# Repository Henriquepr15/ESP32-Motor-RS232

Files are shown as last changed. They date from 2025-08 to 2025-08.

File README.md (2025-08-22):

# ESP32 Motor RS232  

Projeto desenvolvido como parte de um teste prático para posição de Desenvolvedor de Hardware/Firmware.  

## Descrição  
Circuito com ESP32 para acionamento de motor a partir de sinal externo, utilizando reguladores de tensão, conversor buck LM2596, driver de motor e comunicação serial RS232 (MAX3232).  

## Funcionalidades  
- Leitura de sinal externo  
- Acionamento de motor por 10 segundos em nível baixo  
- Envio de mensagens de status via UART RS232  
- LEDs indicadores de funcionamento e debug  

## Estrutura do Projeto  
- Esquemáticos e PCB: Arquivos KiCad  
- Gerber, Drill, PnP e BOM: Saída de fabricação  
- Código em C: Arquivo main.c  
- Documentação: Datasheets e anotações  

## Requisitos de Software  
Código em linguagem C, leitura de entrada digital, controle de saída para o motor, temporização de 10 segundos e comunicação UART.  

## Como Compilar  
O código foi escrito em C padrão, podendo ser adaptado para o ESP32 com ESP-IDF ou Arduino IDE.  

## Requisitos de Hardware  
- ESP32-WROOM-32  
- LM2596 (buck converter)  
- AMS1117-3.3 (regulador LDO)  
- MAX3232 (interface RS232)  
- MOSFET AO3400A  
- Indutor, capacitores, resistores e conectores auxiliares  

## Autor  
Henrique Pires  

## Imagens do projeto  



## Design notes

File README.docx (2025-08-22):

Projeto de Hardware – ESP32 com RS232 e Controle de Motor

Descrição

Este projeto implementa uma placa de desenvolvimento baseada no módulo ESP32-WROOM-32, com suporte a comunicação serial RS-232, controle de motor e alimentação a partir de 12 V.
O circuito inclui conversores de tensão, proteções elétricas e pontos de teste para depuração.

Funcionalidades

- Conversão de 12 V para 5 V (LM2596) e para 3.3 V (AMS1117).
- Comunicação serial compatível com RS-232 (MAX3232 + conector DB9).
- Controle de motor utilizando MOSFET AO3400A e diodo Schottky.
- Proteções contra surtos e inversão de polaridade (fusível, TVS, zener, ferrite bead).
- LEDs indicadores para debug e funcionamento.
- Pontos de teste para facilitar medições.

Estrutura do Projeto

- MCU.kicad_sch – Microcontrolador ESP32 e conexões.
- Power.kicad_sch – Circuito de alimentação.
- Input12V.kicad_sch – Entrada de 12 V e proteções.
- MotorDriver.kicad_sch – Driver de motor.
- RS232.kicad_sch – Comunicação serial RS-232.

Componentes Principais

- ESP32-WROOM-32
- LM2596S-ADJ (buck converter)
- AMS1117-3.3 (LDO)
- MAX3232 (nível RS-232)
- AO3400A (MOSFET de potência)
- Diodos TVS, Schottky e Zener
- Indutor 47 µH (regulador)
- Capacitores e resistores SMD 0805

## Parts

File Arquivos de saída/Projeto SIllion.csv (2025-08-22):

Reference | Qty | Value | DNP | Exclude from BOM | Exclude from Board | Footprint | Datasheet
C5 | 1 | 100µF |  |  |  | Capacitor_SMD:C_0805_2012Metric | ~
C6 | 1 | 1µF |  |  |  | Capacitor_SMD:C_0805_2012Metric | ~
C7,C12,C28 | 3 | 100nF |  |  |  | Capacitor_SMD:C_0805_2012Metric | ~
C8 | 1 | 10 µF |  |  |  | Capacitor_SMD:C_0805_2012Metric | ~
C10 | 1 | 220 µF |  |  |  | Capacitor_SMD:C_0805_2012Metric | ~
C11,C29,C30,C31,C32 | 5 | 100 nF |  |  |  | Capacitor_SMD:C_0805_2012Metric | ~
C13 | 1 | C |  |  |  | Capacitor_SMD:C_0805_2012Metric | ~
C17,C25,C26 | 3 | 10u |  |  |  | Capacitor_SMD:C_0805_2012Metric | ~
C33,C34 | 2 | 100uF |  |  |  | Capacitor_SMD:C_0805_2012Metric | ~
C35,C36 | 2 | 1nF |  |  |  | Capacitor_SMD:C_0805_2012Metric | ~
D1,D9 | 2 | D_TVS |  |  |  | Diode_SMD:D_SMA | ~
D2,D7,D10 | 3 | D_Schottky |  |  |  | Diode_SMD:D_SMA | ~
D8 | 1 | D_Zener |  |  |  | Diode_SMD:D_SOD-123 | ~
D11,D12 | 2 | LED |  |  |  | LED_SMD:LED_0805_2012Metric | ~
F1 | 1 | Fuse |  |  |  | Fuse:Fuse_1812_4532Metric | ~
FB1 | 1 | FerriteBead |  |  |  | Inductor_SMD:L_0805_2012Metric | ~
J1,J3,J5 | 3 | Conn_01x02 |  |  |  | Connector_PinHeader_2.54mm:PinHeader_1x02_P2.54mm_Vertical | ~
J4 | 1 | DE9_Pins |  |  |  | Connector_Dsub:DSUB-9_Pins_Horizontal_P2.77x2.84mm_EdgePinOffset7.70mm_Housed_MountingHolesOffset9.12mm | ~
J6 | 1 | Conn_01x06 |  |  |  | Connector_PinHeader_2.54mm:PinHeader_1x06_P2.54mm_Vertical | ~
L1 | 1 | L |  |  |  | Inductor_SMD:L_Bourns_SRN6045TA | ~
Q3 | 1 | AO3400A |  |  |  | Package_TO_SOT_SMD:SOT-23 | http://www.aosmd.com/pdfs/datasheet/AO3400A.pdf
R8 | 1 | 3,65 kΩ |  |  |  | Resistor_SMD:R_0805_2012Metric | ~
R9 | 1 | 1,20 kΩ |  |  |  | Resistor_SMD:R_0805_2012Metric | ~
R10 | 1 | 100kΩ |  |  |  | Resistor_SMD:R_0805_2012Metric | ~
R11 | 1 | 33kΩ |  |  |  | Resistor_SMD:R_0805_2012Metric | ~
R13 | 1 | 1kΩ |  |  |  | Resistor_SMD:R_0805_2012Metric | ~
R14,R26 | 2 | 100 kΩ |  |  |  | Resistor_SMD:R_0805_2012Metric | ~
R27,R28 | 2 | 10kΩ |  |  |  | Resistor_SMD:R_0805_2012Metric | ~
R29,R30 | 2 | 330Ω |  |  |  | Resistor_SMD:R_0805_2012Metric | ~
SW1,SW2 | 2 | SW_Push |  |  |  | Button_Switch_SMD:SW_SPST_TL3342 | ~
TP1,TP2,TP3,TP4,TP5 | 5 | TestPoint |  |  |  | TestPoint:TestPoint_Pad_1.5x1.5mm | ~
U5 | 1 | LM2596S-ADJ |  |  |  | Package_TO_SOT_SMD:TO-263-5_TabPin3 | http://www.ti.com/lit/ds/symlink/lm2596.pdf
U6 | 1 | MAX3232 |  |  |  | Package_SO:SOIC-16_3.9x9.9mm_P1.27mm | https://datasheets.maximintegrated.com/en/ds/MAX3222-MAX3241.pdf
U7 | 1 | AMS1117-3.3 |  |  |  | Package_TO_SOT_SMD:SOT-223-3_TabPin2 | http://www.advanced-monolithic.com/pdf/ds1117.pdf
U8 | 1 | ESP32-WROOM-32 |  |  |  | RF_Module:ESP32-WROOM-32 | https://www.espressif.com/sites/default/files/documentation/esp32-wroom-32_datasheet_en.pdf

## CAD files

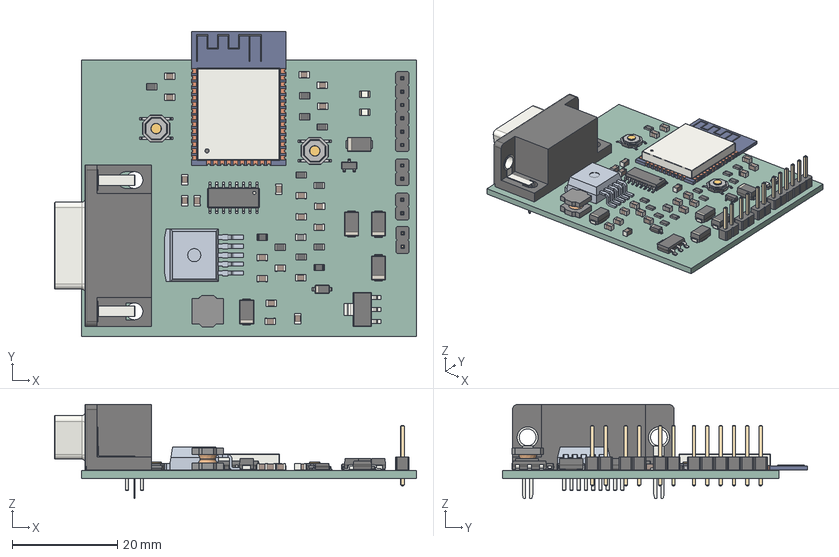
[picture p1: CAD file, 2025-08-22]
Arquivos de saída/Projeto SIllion.step
68.9 x 58.1 x 17.9 mm
C_0805_2012Metric x 20
PinHeader_1x06_P2.54mm_Vertical
Projeto SIllion 1.5.1
R_0805_2012Metric x 11
SW_SPST_TL3342 x 2
SOT-223
D_SMA x 5
SOT-23
ESP32-WROOM-32
L_Bourns_SRN6045TA
L_0805_2012Metric
LED_0805_2012Metric x 2
DSUB-9_Pins_Horizontal_P2.77x2.84mm_EdgePinOffset7.70mm_Housed_ MountingHolesOffset9.12mm
D_SOD-123
PinHeader_1x02_P2.54mm_Vertical x 3
SOIC-16_3.9x9.9mm_P1.27mm
Projeto SIllion_PCB

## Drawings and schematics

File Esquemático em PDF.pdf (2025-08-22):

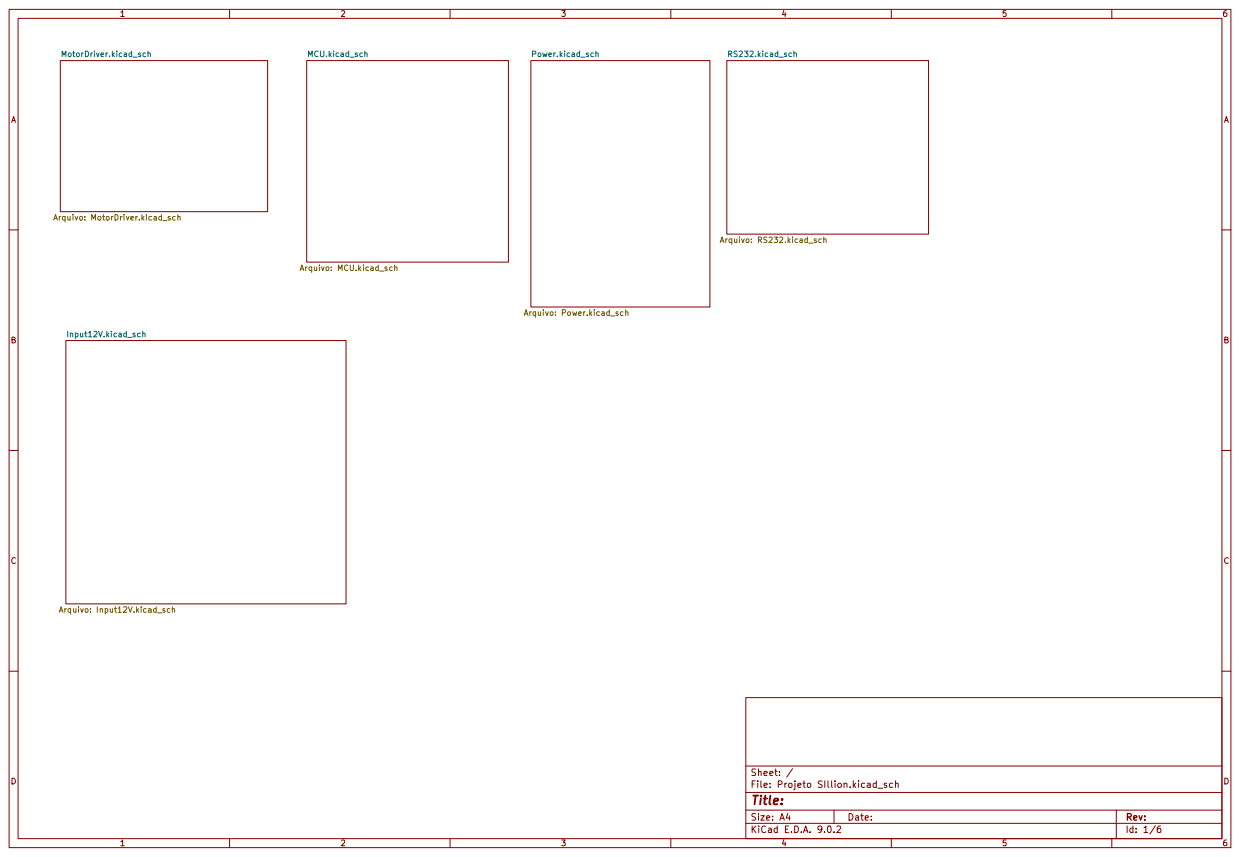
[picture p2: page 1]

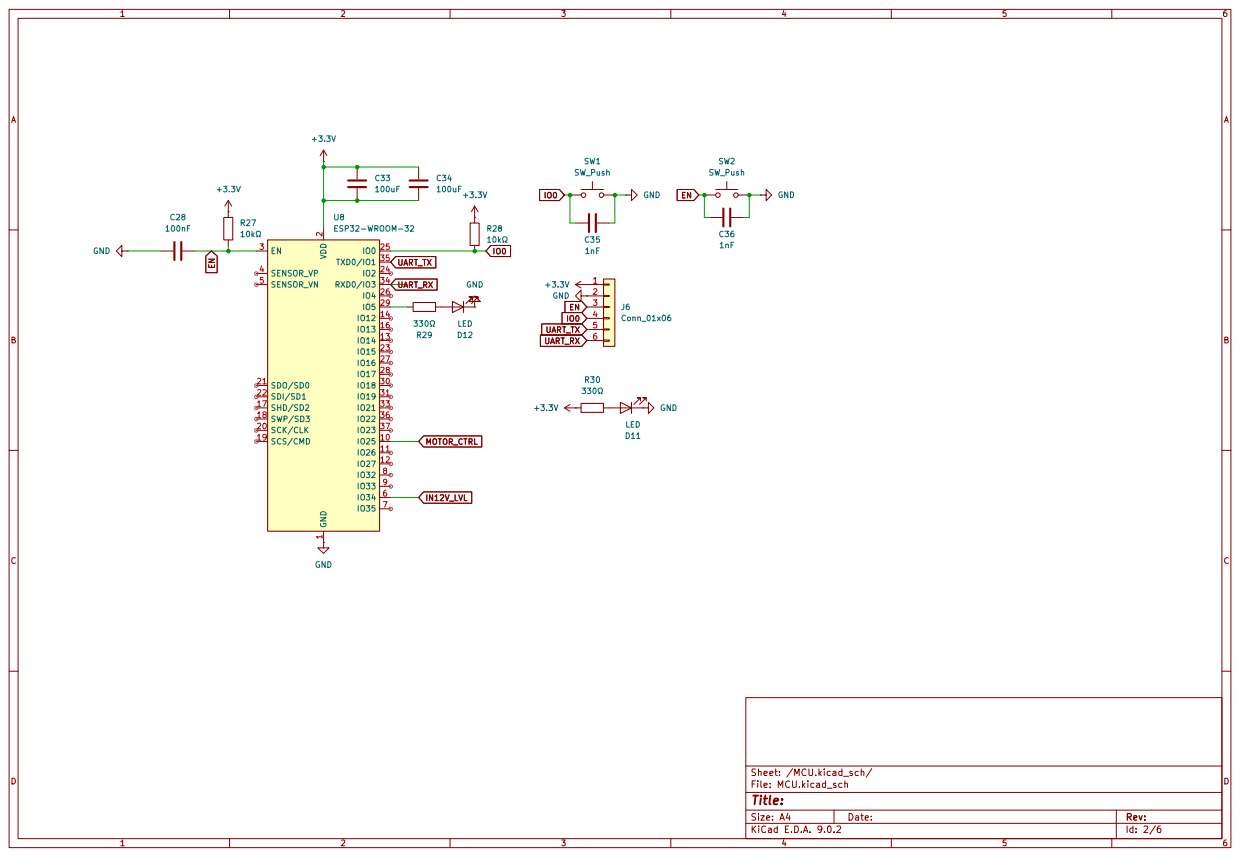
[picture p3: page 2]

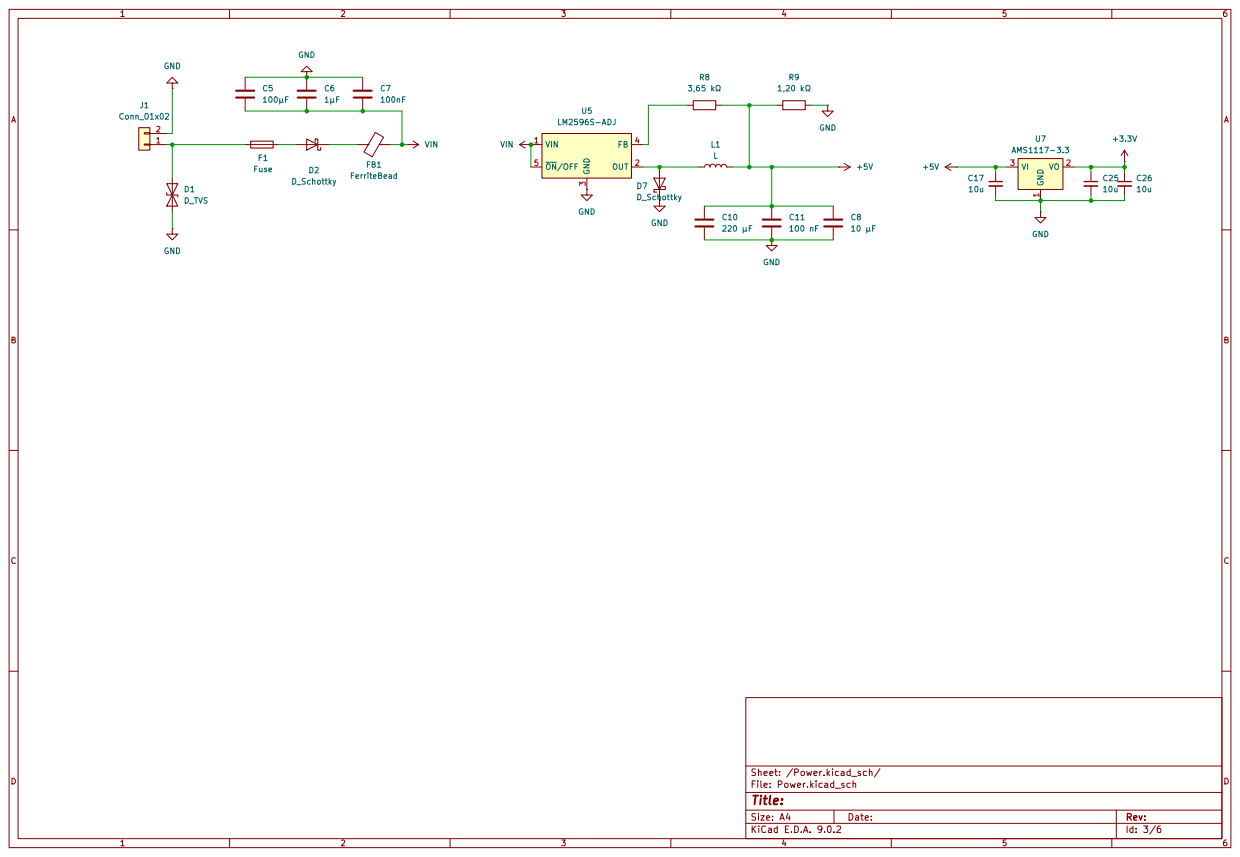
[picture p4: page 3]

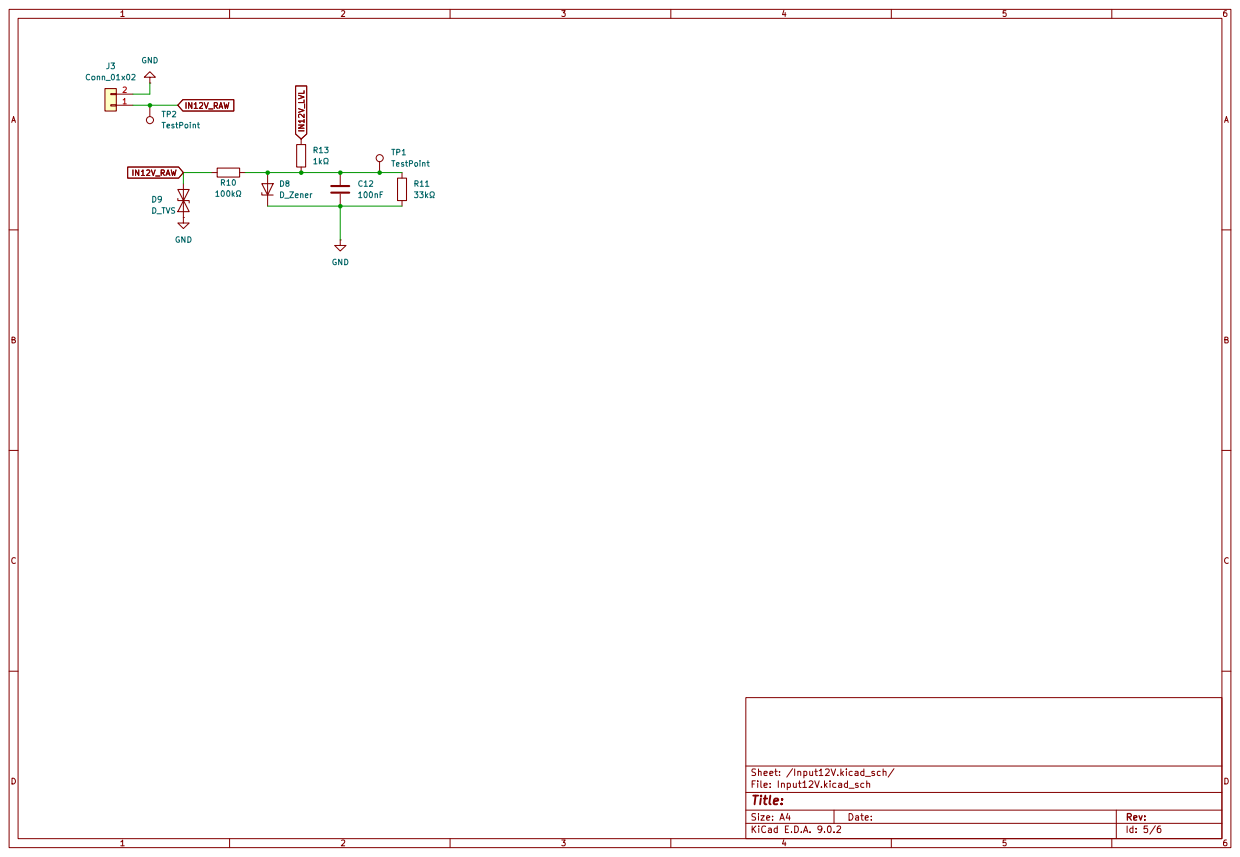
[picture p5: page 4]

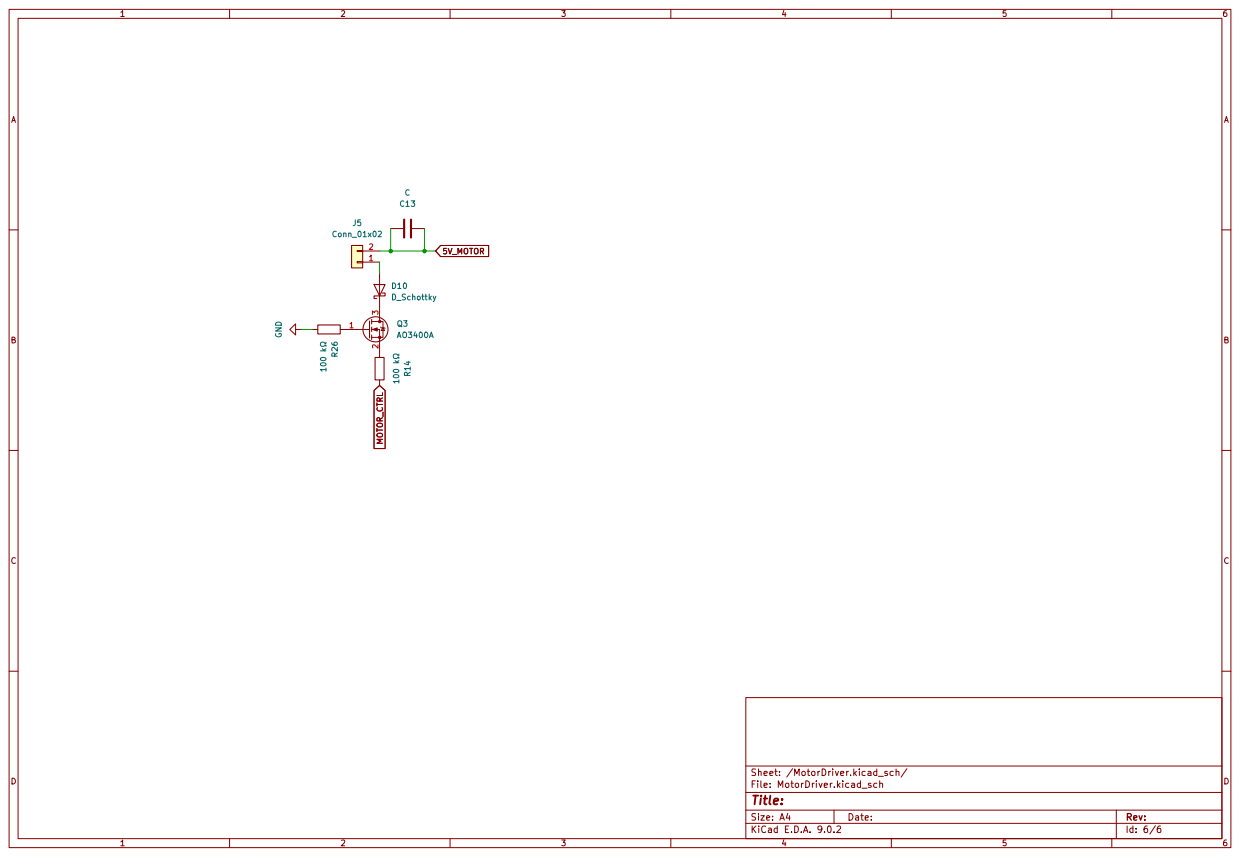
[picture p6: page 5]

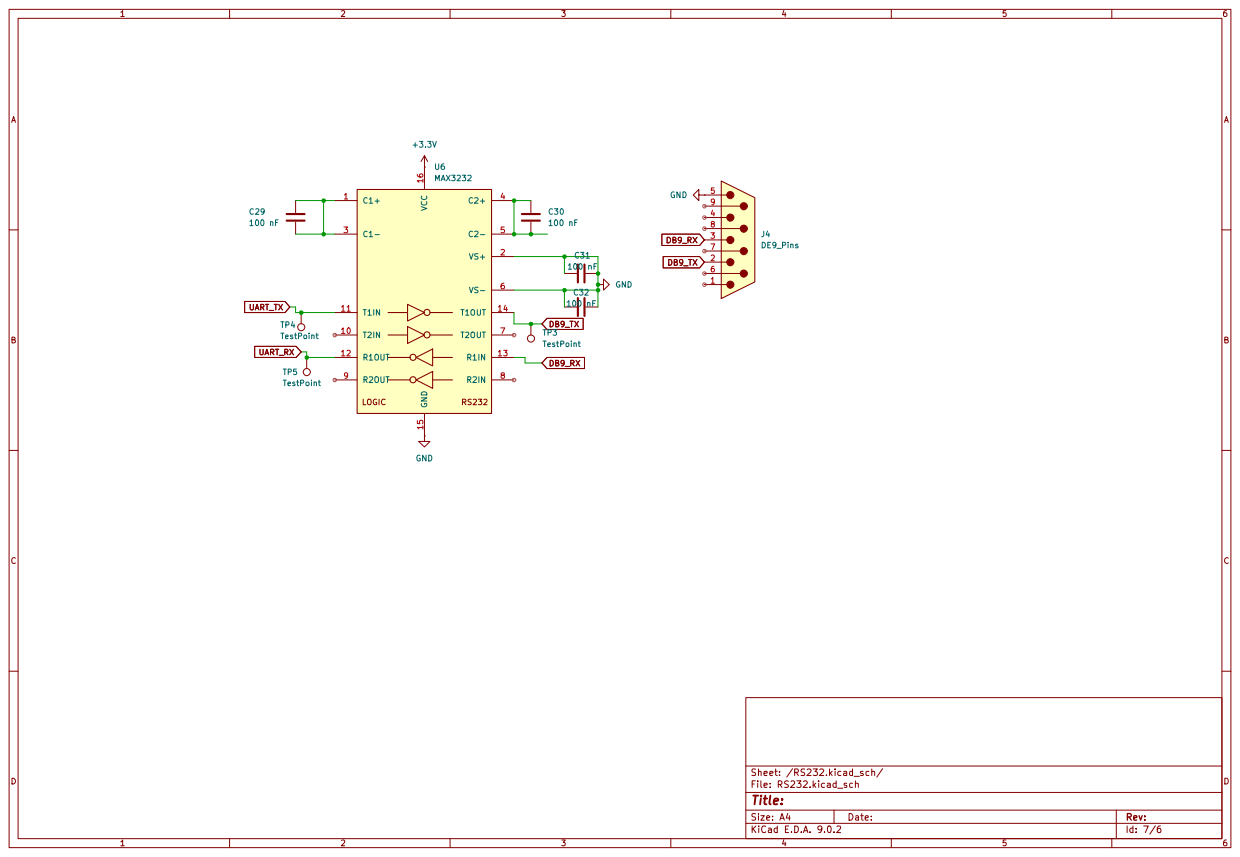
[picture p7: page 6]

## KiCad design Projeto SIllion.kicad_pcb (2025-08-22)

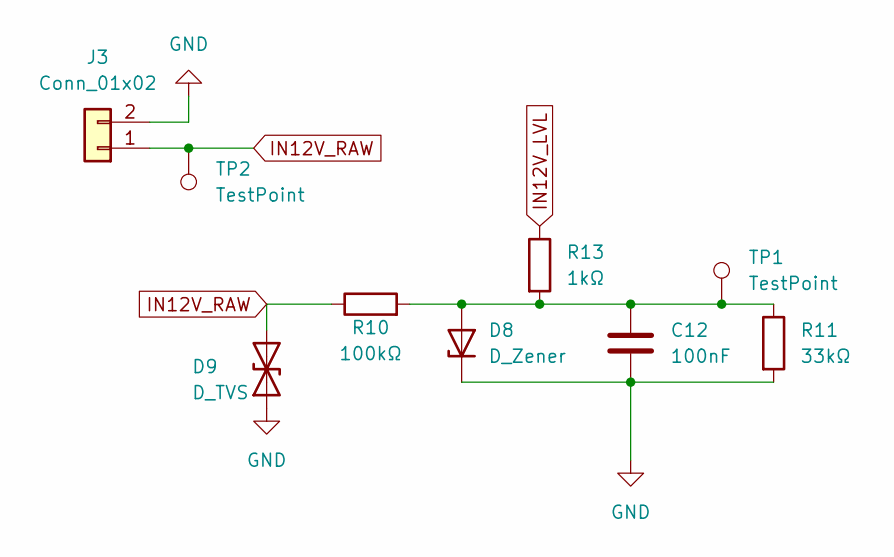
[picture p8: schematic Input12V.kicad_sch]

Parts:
C12: 100nF; C_0805_2012Metric
D8: D_Zener; D_SOD-123
D9: D_TVS; D_SMA
J3: Conn_01x02; PinHeader_1x02_P2.54mm_Vertical
R10: 100kΩ; R_0805_2012Metric
R11: 33kΩ; R_0805_2012Metric
R13: 1kΩ; R_0805_2012Metric
TP1, TP2: TestPoint; TestPoint_Pad_1.5x1.5mm

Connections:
GND: C12.2, D8.1 (K), D9.1 (A1), J3.2, R11.2; also elsewhere on the board
IN12V_LVL: R13.1; also elsewhere on the board
IN12V_RAW: D9.2 (A2), J3.1, R10.1, TP2.1
unnamed: C12.1, D8.2 (A), R10.2, R11.1, R13.2, TP1.1

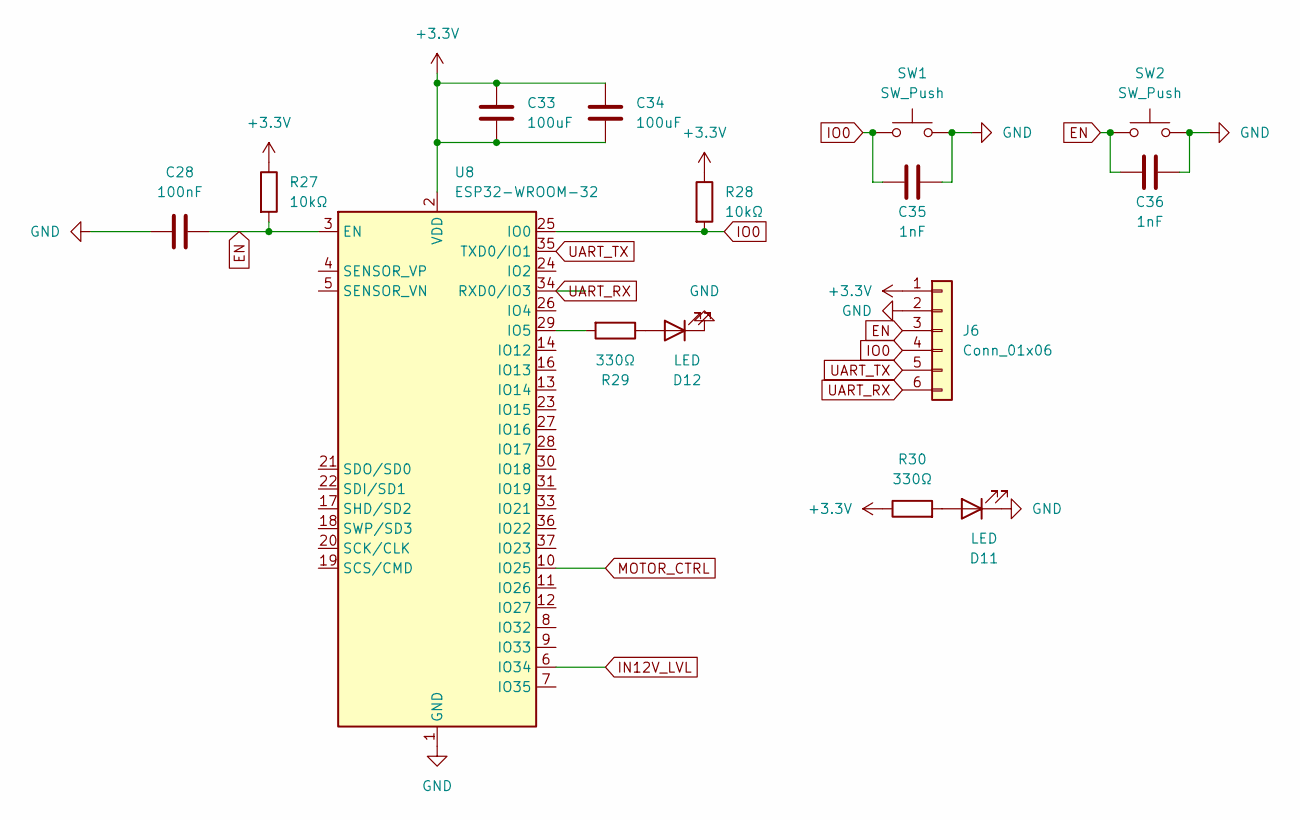
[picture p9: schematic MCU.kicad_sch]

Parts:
C28: 100nF; C_0805_2012Metric
C33, C34: 100uF; C_0805_2012Metric
C35, C36: 1nF; C_0805_2012Metric
D11, D12: LED; LED_0805_2012Metric
J6: Conn_01x06; PinHeader_1x06_P2.54mm_Vertical
R27, R28: 10kΩ; R_0805_2012Metric
R29, R30: 330Ω; R_0805_2012Metric
SW1, SW2: SW_Push; SW_SPST_TL3342
U8: ESP32-WROOM-32

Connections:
+3.3V: C33.1, C33.2, C34.1, C34.2, J6.1, R27.1, R28.1, R30.1, U8.2 (VDD); also elsewhere on the board
EN: C28.2, C36.1, J6.3, R27.2, SW2.1, U8.3 (EN)
GND: C28.1, C35.2, C36.2, D11.1 (K), D12.1 (K), J6.2, SW1.2, SW2.2, U8.1 (GND), U8.15 (GND), U8.38 (GND), U8.39 (GND); also elsewhere on the board
IN12V_LVL: U8.6 (IO34); also elsewhere on the board
IO0: C35.1, J6.4, R28.2, SW1.1, U8.25 (IO0)
MOTOR_CTRL: U8.10 (IO25); also elsewhere on the board
unnamed: D11.2 (A), R30.2
unnamed: D12.2 (A), R29.1
unnamed: R29.2, U8.29 (IO5)
UART_RX: J6.6, U8.34 (RXD0/IO3); also elsewhere on the board
UART_TX: J6.5, U8.35 (TXD0/IO1); also elsewhere on the board

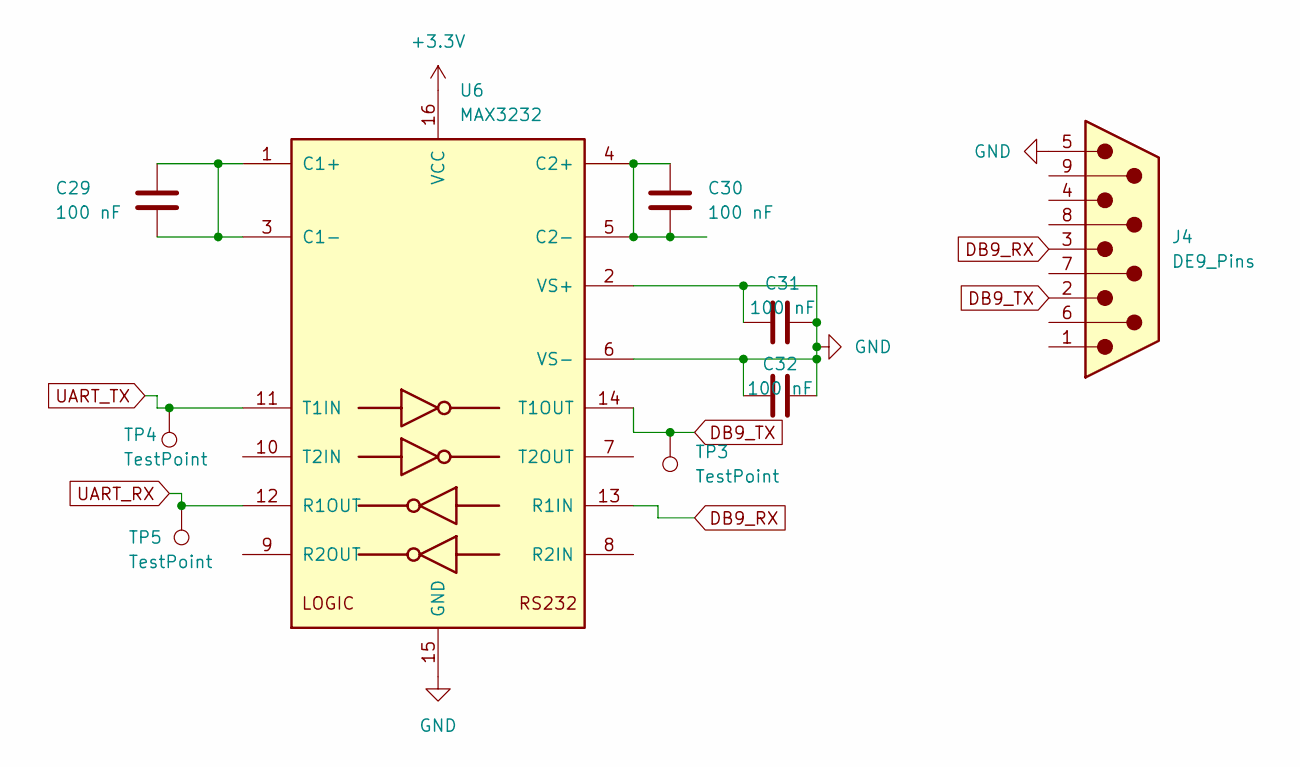
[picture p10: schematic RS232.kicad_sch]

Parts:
C29, C30, C31, C32: 100 nF; C_0805_2012Metric
J4: DE9_Pins; DSUB-9_Pins_Horizontal_P2.77x2.84mm_EdgePinOffset7.70mm_Hou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
TP3, TP4, TP5: TestPoint; TestPoint_Pad_1.5x1.5mm
U6: MAX3232; SOIC-16_3.9x9.9mm_P1.27mm

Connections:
+3.3V: U6.16 (VCC); also elsewhere on the board
DB9_RX: J4.3, U6.13 (R1IN)
DB9_TX: J4.2, TP3.1, U6.14 (T1OUT)
GND: C31.1, C31.2, C32.1, C32.2, J4.5, U6.2 (VS+), U6.6 (VS-), U6.15 (GND); also elsewhere on the board
unnamed: C29.1, C29.2, U6.1 (C1+), U6.3 (C1-)
unnamed: C30.1, C30.2, U6.4 (C2+), U6.5 (C2-)
UART_RX: TP5.1, U6.12 (R1OUT); also elsewhere on the board
UART_TX: TP4.1, U6.11 (T1IN); also elsewhere on the board

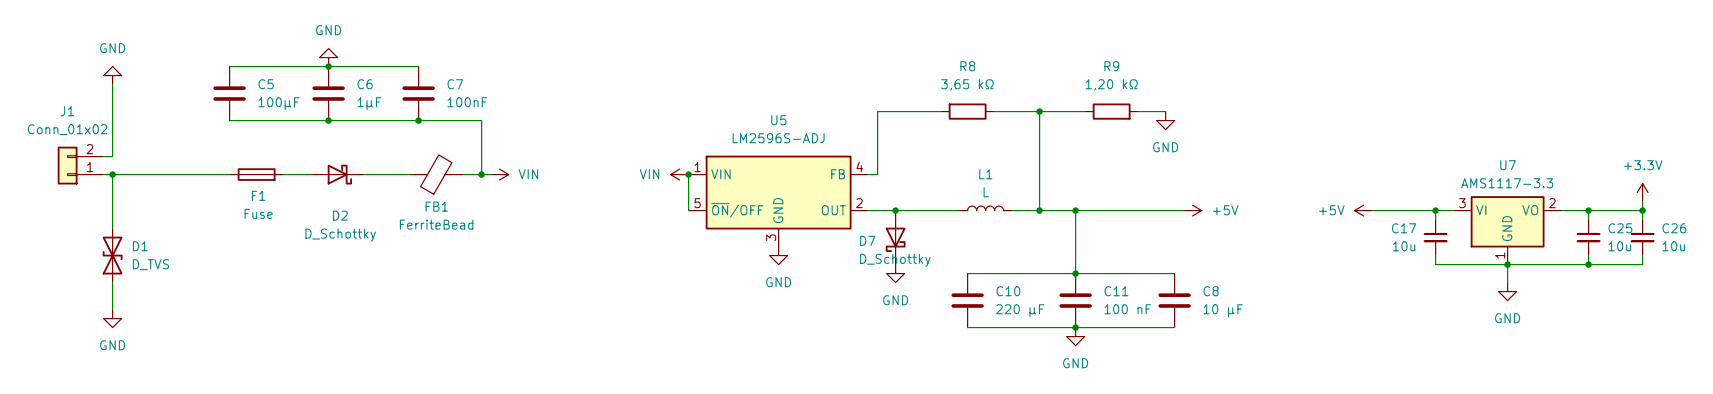
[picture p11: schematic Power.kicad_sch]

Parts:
C5: 100µF; C_0805_2012Metric
C6: 1µF; C_0805_2012Metric
C7: 100nF; C_0805_2012Metric
C8: 10 µF; C_0805_2012Metric
C10: 220 µF; C_0805_2012Metric
C11: 100 nF; C_0805_2012Metric
C17, C25, C26: 10u; C_0805_2012Metric; LCSC Part C15850
D1: D_TVS; D_SMA
D2, D7: D_Schottky; D_SMA
F1: Fuse; Fuse_1812_4532Metric
FB1: FerriteBead; L_0805_2012Metric
J1: Conn_01x02; PinHeader_1x02_P2.54mm_Vertical
L1: L; L_Bourns_SRN6045TA
R8: 3,65 kΩ; R_0805_2012Metric
R9: 1,20 kΩ; R_0805_2012Metric
U5: LM2596S-ADJ; TO-263-5_TabPin3
U7: AMS1117-3.3; SOT-223-3_TabPin2; LCSC Part C347222

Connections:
+3.3V: C25.1, C26.1, U7.2 (VO); also elsewhere on the board
+5V: C8.1, C10.1, C11.1, C17.1, L1.2, R8.1, R9.1, U7.3 (VI)
GND: C5.1, C6.1, C7.1, C8.2, C10.2, C11.2, C17.2, C25.2, C26.2, D1.1 (A1), D7.1 (K), J1.2, R9.2, U5.3 (GND), U7.1 (GND); also elsewhere on the board
unnamed: D1.2 (A2), F1.1, J1.1
unnamed: D2.2 (A), F1.2
unnamed: D2.1 (K), FB1.1
unnamed: D7.2 (A), L1.1, U5.2 (OUT)
unnamed: R8.2, U5.4 (FB)
VIN: C5.2, C6.2, C7.2, FB1.2, U5.1 (VIN), U5.5 (~ON/OFF)

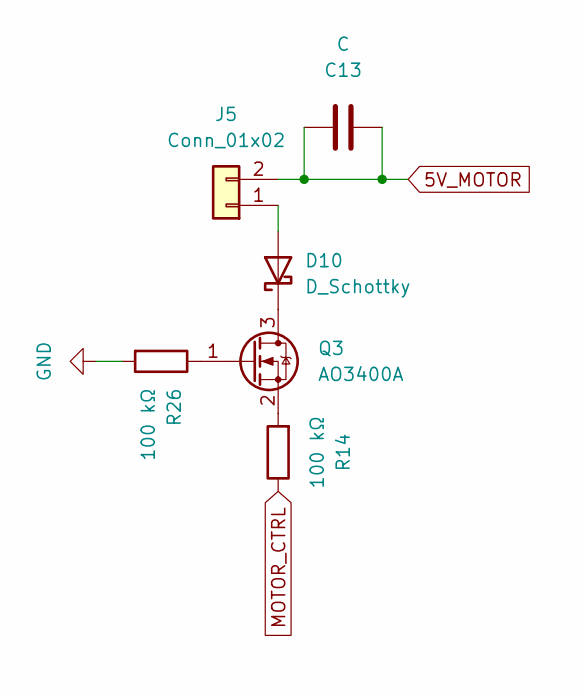
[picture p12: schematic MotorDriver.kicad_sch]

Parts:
C13: C; C_0805_2012Metric
D10: D_Schottky; D_SMA
J5: Conn_01x02; PinHeader_1x02_P2.54mm_Vertical
Q3: AO3400A; SOT-23
R14, R26: 100 kΩ; R_0805_2012Metric

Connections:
5V_MOTOR: C13.1, C13.2, J5.2
GND: R26.2; also elsewhere on the board
MOTOR_CTRL: R14.1; also elsewhere on the board
unnamed: D10.2 (A), J5.1
unnamed: D10.1 (K), Q3.3 (D)
unnamed: Q3.1 (G), R26.1
unnamed: Q3.2 (S), R14.2

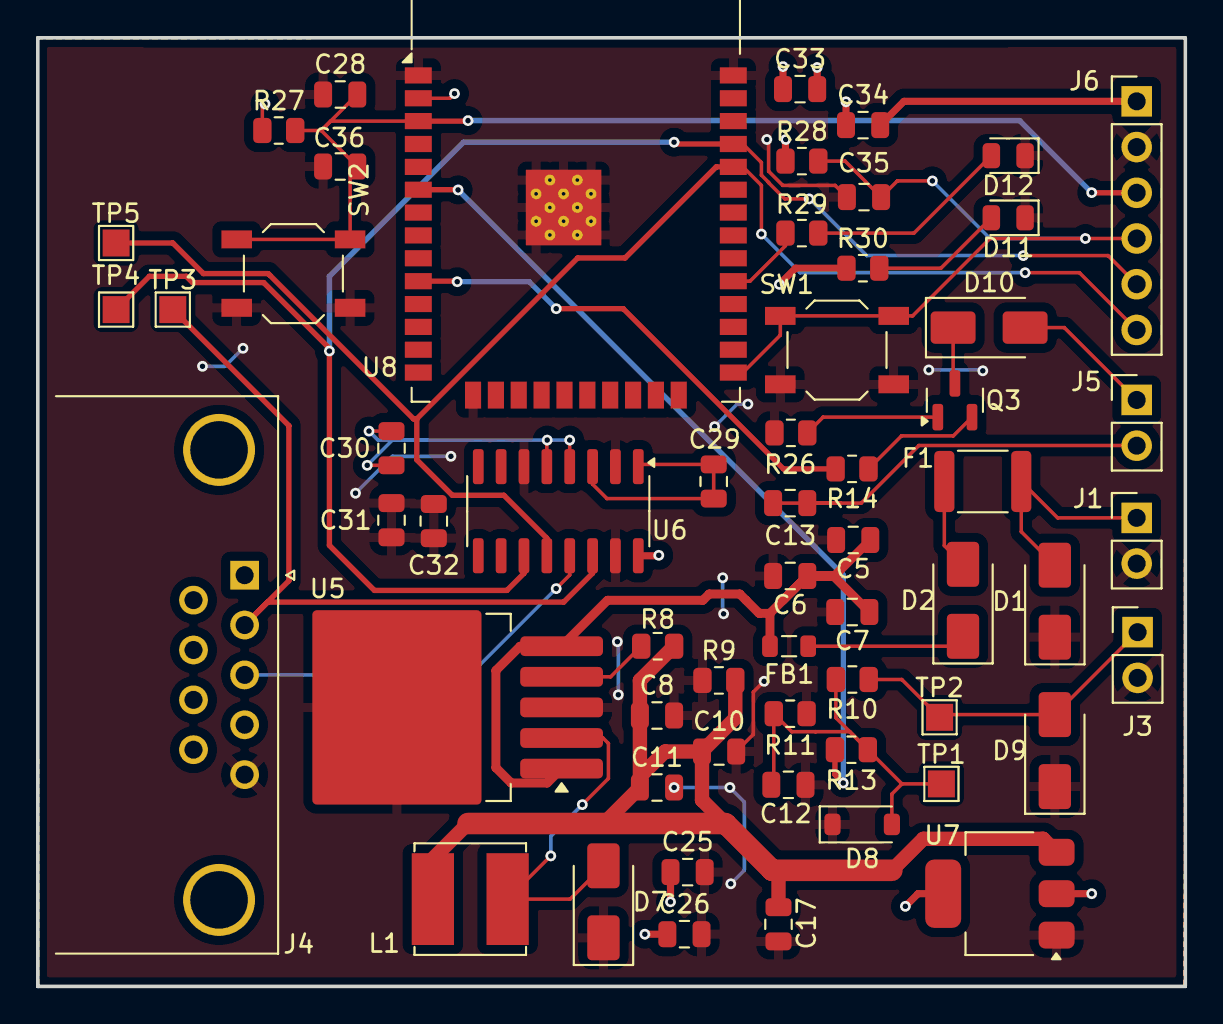
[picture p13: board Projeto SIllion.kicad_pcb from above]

Board: 2 copper layers, 63.8 x 52.7 mm, 59 parts (0 on the bottom side), 29 nets.

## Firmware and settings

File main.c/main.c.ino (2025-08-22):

#include <stdio.h>
#include <stdint.h>
#include <stdbool.h>
#include "driver/gpio.h"
#include "driver/uart.h"
#include "freertos/FreeRTOS.h"
#include "freertos/task.h"

#define INPUT_SIGNAL    GPIO_NUM_4
#define MOTOR_OUTPUT    GPIO_NUM_5
#define UART_PORT       UART_NUM_1

void init_gpio(void);
void init_uart(void);
void send_uart_message(const char *msg);

void app_main(void) {
    init_gpio();
    init_uart();

    while (1) {
        int signal = gpio_get_level(INPUT_SIGNAL);

        if (signal == 0) {
            gpio_set_level(MOTOR_OUTPUT, 1);
            send_uart_message("Motor ON\r\n");
            vTaskDelay(pdMS_TO_TICKS(10000));
            gpio_set_level(MOTOR_OUTPUT, 0);
            send_uart_message("Motor OFF\r\n");
        }

        vTaskDelay(pdMS_TO_TICKS(100));
    }
}

void init_gpio(void) {
    gpio_config_t io_conf = {0};
    io_conf.intr_type = GPIO_INTR_DISABLE;
    io_conf.mode = GPIO_MODE_INPUT;
    io_conf.pin_bit_mask = (1ULL << INPUT_SIGNAL);
    io_conf.pull_up_en = GPIO_PULLUP_ENABLE;
    gpio_config(&io_conf);

    io_conf.intr_type = GPIO_INTR_DISABLE;
    io_conf.mode = GPIO_MODE_OUTPUT;
    io_conf.pin_bit_mask = (1ULL << MOTOR_OUTPUT);
    io_conf.pull_up_en = GPIO_PULLUP_DISABLE;
    gpio_config(&io_conf);
}

void init_uart(void) {
    uart_config_t uart_config = {
        .baud_rate = 9600,
        .data_bits = UART_DATA_8_BITS,
        .parity    = UART_PARITY_DISABLE,
        .stop_bits = UART_STOP_BITS_1,
        .flow_ctrl = UART_HW_FLOWCTRL_DISABLE
    };
    uart_driver_install(UART_PORT, 1024, 0, 0, NULL, 0);
    uart_param_config(UART_PORT, &uart_config);
    uart_set_pin(UART_PORT, GPIO_NUM_17, GPIO_NUM_16, UART_PIN_NO_CHANGE, UART_PIN_NO_CHANGE);
}

void send_uart_message(const char *msg) {
    uart_write_bytes(UART_PORT, msg, strlen(msg));
}
